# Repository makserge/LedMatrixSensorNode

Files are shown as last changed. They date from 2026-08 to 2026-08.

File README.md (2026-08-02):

# Led Matrix Node

A custom build based on a "LED Music Spectrum Rhythm Lights Voice Sensor 1624 RGB Atmosphere Level Indicator with Clock Display" panel driven by a Seeed XIAO ESP32-S3 Plus. It shows the time, ambient CO₂/temperature, a live audio spectrum analyzer, scrolling alert messages, or MQTT-pushed pixel-art icons; tracks room presence and people via mmWave radar; and is fully controllable and observable over MQTT (with Home Assistant auto-discovery).

---

## Architecture

The firmware is split into independent FreeRTOS tasks, each pinned to a core and communicating through small, mutex/queue-protected shared state rather than globals:

| Task | Core | Responsibility |
|---|---|---|
| `DisplayTask` | 1 | Owns the matrix, view state machine, CO₂ alarm/beep logic, button input, OTA progress rendering |
| `NtpClockTask` | 1 | Keeps wall-clock time via NTP, pushes formatted strings through a queue |
| `MqttTask` | 1 | Connects/reconnects to the broker, publishes sensor + radar data, dispatches incoming commands |
| `SpectrumAnalyzerTask` | 2 (audio priority) | Decodes the audio stream, runs dual FFTs, drives per-band ballistics |
| `Co2Task`, `TempHumTask`, `LightTask`, `LD2412Task`, `LD2450Task` | 0 | Poll their respective sensors on independent intervals |
| `LedMatrix` internal display engine | 1 | Bit-bangs the panel's HUB75-style interface from double-buffered R/G/B column data |

I²C sensors (SCD4x CO₂, HTU21D temp/humidity, BH1750 light) share the bus behind a single `i2cMutex` (`i2c_mutex.h`) — every I²C transaction, including `begin()` calls, must be wrapped in `xSemaphoreTake`/`Give`.

Rendering follows a **Command Pattern**: each screen lives in its own `src/screen_*.cpp` file (`screen_clock`, `screen_temp`, `screen_co2`, `screen_spectrum`, `screen_alert`, `screen_ota`, `screen_icon`), all declared through one `screen_renderers.h` registry and dispatched from a single `switch` in `displayTask`.

**Background task handles** are centralized in `task_registry.h`/`.cpp` so the whole sensor/MQTT layer can be suspended and resumed as a unit (used during OTA — see below).

---

## Hardware / Pinout

Board: Seeed XIAO ESP32-S3 Plus (Arduino-style `Dx` pin aliases used for most GPIO), driving the 1624 RGB Atmosphere Level Indicator panel's HUB75-style interface.

| Function | Pin(s) |
|---|---|
| Panel RGB data | `R1`=42, `G1`=D3, `B1`=10 |
| Panel clock/latch/enable | `CLK`=D4, `LAT`=D6, `OE`=D5 |
| Panel row address | `A`=D0, `B`=38, `C`=39 |
| Panel chip-selects | `L_EN`=40, `M_EN`=41, `R_EN`=D2 |
| I²C bus (CO₂/temp/light sensors) | `SDA`=12, `SCL`=7 |
| Beeper | 13 |
| Mode button | D9 (`INPUT_PULLUP`) |
| Power toggle button | D10 (`INPUT_PULLUP`) |
| LD2412 presence (digital) | D1 |
| LD2450 UART (Serial1) | `RX`=11, `TX`=D7 @ 256000 baud |

The panel is driven by a **hand-rolled HUB75-style engine** (`led_matrix.cpp`/`.h`): it bit-bangs GPIO registers directly, splits the 24-column panel across 3 chip-select groups of 8, and controls brightness with on-time PWM within a fixed 180µs column window. Text is rendered with a hand-authored 4×14 PROGMEM font (`font_4x14.h`) covering `0–9`, `A–Z`, `:`, `.`, and a degree glyph mapped to `*` in source strings.

---

## Configuration

Copy `secrets.example.h` to `secrets.h` and fill in your own values (git-ignored):

```cpp
static const char* const MQTT_HOST = "192.168.x.x";
static const char* const MQTT_USER = "your_mqtt_user";
static const char* const MQTT_PASS = "your_mqtt_password";
static const char* const AUDIO_STREAM_URL = "http://192.168.x.x:8000/stream.wav";
static const char* const WIFI_BACKUP_SSID = "backup-network";
static const char* const WIFI_BACKUP_PASS = "backup-password";
```

`WIFI_BACKUP_SSID`/`PASS` are optional — leave blank to disable the fallback network.

### Library dependencies

`WiFiManager`, `ElegantOTA`, `ESPAsyncWebServer`, `PubSubClient`, `ArduinoJson`, `Preferences`, `SensirionI2cScd4x`, `HTU21D`, `BH1750`, `LD2450`, and `AudioTools` (with `AudioRealFFT`).

---

## Display & View Management

- **Views:** `VIEW_TIME`, `VIEW_TEMP_DATA`, `VIEW_CO2`, `VIEW_SPECTRUM`, `VIEW_CUSTOM_MSG`, `VIEW_CUSTOM_ICON`.
- **Persistence:** the active view *and* the clock color are stored in NVS (`Preferences`, namespace `"display"`) and restored on boot. Transient views (custom message, icon, CO₂ popup) are set via `setView()` and are **never** persisted — only deliberate mode changes via `selectView()` (button/MQTT) update the boot-time default.
- **Auto-return:** temp/CO₂ auto-return after `DISPLAY_AUTO_RETURN_DELAY_MS` (5s). Scrolling messages and icons expire after their own duration or (for messages) 3 full scroll passes.
- **View arbitration:**
  - Spectrum's automatic entry **cannot interrupt** an active custom message or icon still within its display window.
  - Once the user manually switches to a view other than spectrum (button or MQTT `display/mode`), spectrum's automatic re-entry is **suppressed** until the user manually selects spectrum again — audio staying active no longer yanks the display back.
  - Custom messages and MQTT-pushed icons **restore the view that was active before they interrupted it** (including spectrum) once they expire, rather than always falling back to the clock — the same pattern the CO₂ alarm popup already used. Manually cycling to temp/CO₂ via the button still auto-returns to the clock after 5s, unchanged — that's deliberate browsing, not an interruption.
- **Buttons:** mode button cycles `TIME → TEMP → CO2 → SPECTRUM` (300ms debounce); power button blanks/wakes the panel without stopping any background task.
- **Persistent clock color:** MQTT-settable, survives reboots (see [MQTT Topics](#mqtt-topics)).
- **No artificial startup delay** — `displayTask` initializes the matrix immediately rather than waiting a fixed period before starting.

## RLE Icon Display

Pixel-art icons can be pushed to the panel over MQTT as a compact run-length-encoded binary payload:

**Topic:** `led_matrix_node/display/icon`
**Payload:** repeating runs — `[runLength, r, g, b]`, one byte each — covering up to 384 pixels (24×16) in row-major order. Colors are quantized to the panel's native 3-bit palette (each channel thresholds at >127).

Two payload formats are accepted, auto-detected:

- **ASCII hex string** (recommended — plain text, works from MQTT Explorer's payload box or Home Assistant's `mqtt.publish` service with no binary handling needed):
  ```
  C0000000C0FFFFFF
  ```
  (top half of the panel black, bottom half white — 192 black pixels + 192 white pixels = 384 total)

  ```yaml
  # Home Assistant automation action
  action: mqtt.publish
  data:
    topic: led_matrix_node/display/icon
    payload: "C0000000C0FFFFFF"
  ```

- **Raw binary** is also accepted (auto-detected) for programmatic publishing, but the hex-string format above is recommended for all use cases — it works identically from a script, MQTT Explorer, or Home Assistant with no extra encoding step.

The icon is buffered server-side and **redrawn every frame** while `VIEW_CUSTOM_ICON` is active (it does not persist as the boot default, and is protected from spectrum's automatic re-entry the same way custom messages are), then auto-returns to the previous rotation after `ICON_DISPLAY_DURATION_MS` (15s).

> ⚠️ **If using raw binary instead of the hex format above:** `mosquitto_pub -m "\xc0\x00..."` does **not** interpret `\xNN` as byte escapes — it sends those characters literally as ASCII text. Use `printf '\xc0\x00...' | mosquitto_pub -t ... -l` (or `-f` with a file), or build the payload as real bytes in a script. This is exactly the trap the hex-string format above avoids — prefer it unless you have a specific reason to send raw binary.

### Example icons

Two ready-to-use icons for a washing-machine status use case — publish either directly to `led_matrix_node/display/icon`.

**Washing in progress:**
```
.....#############......
.....#...........#......
.....#...........#......
.....#...........#......
.....#...........#......
.....#############......
.....#...........#......
.....#.....#.....#......
.....#....#.#....#......
.....#...#...#...#......
.....#..#.....#..#......
.....#...#GGG#...#......
.....#....#G#....#......
.....#.....#.....#......
.....#...........#......
.....#############......
```
```
050000000D00FF000B0000000100FF000B0000000100FF000B0000000100FF000B0000000100FF000B0000000100FF000B0000000100FF000B0000000100FF000B0000000100FF000B0000000D00FF000B0000000100FF000B0000000100FF000B0000000100FF00050000000100FF00050000000100FF000B0000000100FF00040000000100FF00010000000100FF00040000000100FF000B0000000100FF00030000000100FF00030000000100FF00030000000100FF000B0000000100FF00020000000100FF00050000000100FF00020000000100FF000B0000000100FF00030000000100FF00030000FF0100FF00030000000100FF000B0000000100FF00040000000100FF00010000FF0100FF00040000000100FF000B0000000100FF00050000000100FF00050000000100FF000B0000000100FF000B0000000100FF000B0000000D00FF0006000000
```

**Washing complete** (same machine, shifted left with a checkmark badge alongside):
```
.#############..........
.#...........#..........
.#...........#..........
.#...........#..........
.#...........#........##
.#############.......##.
.#...........#.......##.
.#.....#.....#......##..
.#....#.#....#......##..
.#...#...#...#..#..##...
.#..#.....#..#..##.##...
.#...#GGG#...#...###....
.#....#G#....#...###....
.#.....#.....#....#.....
.#...........#..........
.#############..........
```
```
010000000D00FF000B0000000100FF000B0000000100FF000B0000000100FF000B0000000100FF000B0000000100FF000B0000000100FF000B0000000100FF000B0000000100FF00080000000200FF00010000000D00FF00070000000200FF00020000000100FF000B0000000100FF00070000000200FF00020000000100FF00050000000100FF00050000000100FF00060000000200FF00030000000100FF00040000000100FF00010000000100FF00040000000100FF00060000000200FF00030000000100FF00030000000100FF00030000000100FF00030000000100FF00020000000100FF00020000000200FF00040000000100FF00020000000100FF00050000000100FF00020000000100FF00020000000200FF00010000000200FF00040000000100FF00030000000100FF00030000FF0100FF00030000000100FF00030000000300FF00050000000100FF00040000000100FF00010000FF0100FF00040000000100FF00030000000300FF00050000000100FF00050000000100FF00050000000100FF00040000000100FF00060000000100FF000B0000000100FF000B0000000D00FF000A000000
```

(`#`=green outline, `G`=blue door accent — `.` renders as black/off)

## NTP Clock

Syncs via `configTzTime` against `pool.ntp.org`. Formats `HH:MM` with a blinking colon; shows `SYNC` until the first successful fix.

## Environmental Sensors

- **CO₂ (Sensirion SCD4x):** 0-ppm glitch rejection, watchdog restart on stalled measurement cycles.
- **Temperature/Humidity (HTU21D):** sanity-bounded reads (`hum < 101%`, `temp > -40°C`).
- **Ambient Light (BH1750):** drives automatic matrix brightness via a smoothed exponential curve, low-pass filtered to avoid visible jumps.

## CO₂ Alarm System

Hysteresis band between `CO2_WARNING_THRESHOLD` (1000ppm) and `CO2_ALARM_LOW_THRESHOLD` (900ppm); a recurring red popup with quiet-hours-gated beeping (08:00–22:00), safety-timeout-bounded so it can never get stuck on screen.

## Audio Spectrum Analyzer

Dual-resolution FFT (2048-pt bass / 1024-pt mid-high) driving a 24-column VU-style display with Gaussian-weighted log-frequency bands, noise gating, compression, adaptive AGC, and tilt EQ. Auto-enters `VIEW_SPECTRUM` on active audio (respecting the view-arbitration rules above) and fades to sleep on sustained silence.

**Peak-dot physics** are ported from [`audioMotion-analyzer`](https://github.com/hvianna/audioMotion-analyzer)'s gravity-based fall model: rather than dropping at a fixed rate, each band's peak indicator accelerates continuously after `BALLISTICS_PEAK_HOLD_MS` (700ms hold), governed by `SPECTRUM_PEAK_GRAVITY_STEPS_PER_S2` — tune this constant to make peaks fall faster/slower/more "floaty". The audio transport (HTTP stream ingestion, dual-FFT band mapping) and silence-detection state machine (rolling average, sleep-fade, presence-aware view auto-return) are unchanged from the existing design, which was already a log-frequency, Gaussian-weighted mapping in its own right.

## mmWave Radar

**LD2412** — binary presence on a single GPIO. **LD2450** — up to 3 tracked targets over UART with a sign-fix for its two's-complement quirk and a watchdog that fully re-inits the link on stall (UART desync doesn't self-heal the way the frame-redrawn matrix does).

## WiFi & OTA

- `WiFiManager` captive portal (180s timeout) for first-time setup, followed by an automatic **backup network** attempt (`WIFI_BACKUP_SSID`/`PASS`, `WIFI_BACKUP_TIMEOUT_MS` = 15s) if the primary/portal path fails, before finally restarting.
- Post-connect, the panel shows the assigned IP address (green, 15s) — protected from being interrupted by spectrum auto-entry.
- **OTA updates (`ElegantOTA` at `/update`)** now take over the whole node:
  - The panel shows a static **"OTA"** for the entire transfer, then automatically resumes whatever view was active beforehand — no explicit "restore" logic needed, since the underlying view state is simply untouched while the OTA flag is set.
  - All background tasks are suspended for the duration of the update and resumed afterward — sensors/MQTT (`task_registry.h`) *and* the audio pipeline (stream ingestion, ballistics, spectrum view-switching), freeing CPU and I²C/UART/network bandwidth for the flash write.
  - Buttons, CO₂ alarm logic, and normal view rendering are all paused until the update finishes.
  - **`LedMatrix::displayTaskEngine` is `IRAM_ATTR`, and its pin toggling uses `gpio_ll_set_level()` instead of `digitalWrite()`.** ESP32 flash writes briefly disable both cores' instruction cache; `IRAM_ATTR` on the function alone isn't sufficient, since `digitalWrite()` is a real call out to code that may itself live in flash — if that call stalls mid-refresh with OE left blanked, the panel visibly blinks for the stall's duration. `gpio_ll_set_level()` is a `static inline` register accessor with no external call, so it inherits the caller's IRAM residency and stays safe throughout an OTA write.
- `/wifi-reset` clears saved WiFi credentials and reboots into the config portal.

---

## MQTT Topics

### Commands (subscribe)

| Topic | Payload | Effect | Example |
|---|---|---|---|
| `led_matrix_node/display/mode` | `time` \| `temp` \| `co2` \| `spectrum` | Selects a view, persists across reboots | `mosquitto_pub -t led_matrix_node/display/mode -m "co2"` |
| `led_matrix_node/display/message` | text (≤31 chars, auto-uppercased) | Scrolling red alert, up to 15s or 3 passes | `mosquitto_pub -t led_matrix_node/display/message -m "Package delivered"` |
| `led_matrix_node/display/power` | `1` \| `0` | Panel on/off | `mosquitto_pub -t led_matrix_node/display/power -m "0"` |
| `led_matrix_node/display/color` | `RRGGBB` / `#RRGGBB` / `r,g,b` | Sets and persists the clock color | `mosquitto_pub -t led_matrix_node/display/color -m "FF8800"` |
| `led_matrix_node/display/icon` | RLE hex string (see above) | Shows a pixel-art icon for 15s | see examples above |
| `led_matrix_node/beeper` | any | Single 100ms beep | `mosquitto_pub -t led_matrix_node/beeper -m "1"` |

### State (publish)

| Topic | Format | Interval | Notes |
|---|---|---|---|
| `led_matrix_node/sensors/state` | `{"co2":812,"temp":21.4,"hum":47.2,"lux":18.6}` | 10s | Skipped while `co2 == 0` |
| `led_matrix_node/sensors/status` | `online` / `offline` | on connect / LWT | Retained |
| `led_matrix_node/radar/ld2412` | `1` / `0` | 1s | Retained |
| `led_matrix_node/radar/ld2450` | `{"targets":[...],"count":N}` | 1s | Up to 3 targets |

```bash
mosquitto_sub -v -t 'led_matrix_node/#'
```

### Home Assistant Auto-Discovery

Retained discovery configs are published under `homeassistant/sensor/Led_Matrix_Node_{id}/config` for `co2`, `temp`, `hum`, `lux` on every broker connection.

---

## Key Tunables (`constants.h`)

| Category | Constant | Value |
|---|---|---|
| Display | `DISPLAY_AUTO_RETURN_DELAY_MS` | 5000ms |
| WiFi | `WIFI_CONFIG_TIMEOUT` / `WIFI_BACKUP_TIMEOUT_MS` | 180s / 15000ms |
| WiFi | `WIFI_IP_DISPLAY_DURATION_MS` | 15000ms |
| OTA | `OTA_TEXT_DISPLAY_MS` | 2000ms |
| Icon | `ICON_DISPLAY_DURATION_MS` | 15000ms |
| CO₂ Alarm | `CO2_WARNING_THRESHOLD` / `CO2_ALARM_LOW_THRESHOLD` | 1000 / 900 ppm |
| CO₂ Alarm | `CO2_ALARM_START_HOUR`–`END_HOUR` | 08:00–22:00 |
| Matrix | `MATRIX_WIDTH` / `MATRIX_HEIGHT` | 24 / 16 |
| MQTT | `MQTT_PUBLISH_INTERVAL` / `MQTT_RADAR_PUBLISH_INTERVAL` | 10000ms / 1000ms |
| Radar | `LD2450_DATA_TIMEOUT_MS` | 10000ms |
| Spectrum | `SPECTRUM_AGC_TARGET_LED`, `SPECTRUM_TILT_DB_PER_OCTAVE` | 8.0, 3dB/oct |
| Spectrum | `SPECTRUM_PEAK_GRAVITY_STEPS_PER_S2` | 220.0 (steps/s²) |

See `constants.h` for the full list.

---

## Security Notes

- `secrets.h` contains live credentials (primary + backup WiFi, MQTT, audio stream URL) — keep it out of version control.
- The web UI (`/`, `/update`, `/wifi-reset`) is unauthenticated on the local network.

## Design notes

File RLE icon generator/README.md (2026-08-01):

# 24x16 RLE Icon Editor and MQTT Publisher

A lightweight, high-utility web application designed to create, edit, and convert custom pixel artwork into custom Run-Length Encoded (RLE) Hex streams. It is specifically optimized for hardware displays with rectangular pixels (2:1 width-to-height ratio) and features a bidirectional compiler that can both pack canvas data and unpack/decode existing RLE strings back into editable pixels.

---

## Features

- **Interactive 24x16 Matrix Editor:** Click and drag to paint pixel art in real-time. The browser UI grid matches the hardware's 2:1 rectangular aspect ratio natively (What You See Is What You Get).
- **Instant Drag and Drop Image Converter:** Drop standard images (.png, .jpg, .webp) to automatically downscale and map them onto the 24x16 display grid.
- **Advanced Back-Converter / Decompressor:** Paste a raw RLE hex string (or an entire mosquitto_pub terminal command line) to unpack it back into fully editable grid pixels.
- **Custom Real-Time RLE Compiler:** Generates compact data streams using a 1-byte count + 3-byte RGB structure.
- **Live MQTT Command Generator:** Auto-interpolates Host, Username, and Password fields directly into a standalone shell execution script.
- **Persistent Configuration Storage:** Saves your MQTT configuration variables locally using localStorage so you never have to re-type them.

---

## Project Structure

To run the application, ensure the following 3 core files are saved in the exact same directory. No local web server or terminal configuration is required to execute the workspace:

```text
├── rle_icon_generator.html   # Main application interface and engine
├── style.css                 # Dark-mode workspace and fluid 2:1 grid layout styling
└── app.js                    # Core logic (drawing, RLE compression/decompression, image scaling)
```

---

## Understanding the RLE Hex Format

The compiler uses a simple 4-Byte Packet Compression Logic optimized for hardware components (like ESP32/Arduino display drivers):
- **1st Byte (2 Hex Characters):** The Run Count (Repetition depth up to 255 / Hex FF).
- **2nd, 3rd, 4th Byte (6 Hex Characters):** The 24-bit RGB Color Code in UpperCase Hex format.

### Example:
- **`1E000000`** translates to `1E` (30 in decimal) pixels of `000000` (Pure Black).
- **`0CFFFFFF`** translates to `0C` (12 in decimal) pixels of `FFFFFF` (Pure White).

---

## Technical Limitations and Pixel Aspect Ratio

While the drag-and-drop workflow is completely automated, converting standard graphics into a restrictive 24x16 grid with 2:1 rectangular pixels requires specific data handling considerations:

### 1. 2:1 Pixel Aspect Ratio (Physical 3:1 Matrix Screen)
- **The 2:1 Rule:** Each pixel on your physical LED matrix is twice as wide as it is tall (2w x 1h). 
- **Physical Aspect Ratio:** Although the grid resolution is 24x16 (a 3:2 index count), the physical shape of the running screen is 3:1 widescreen (24 x 2 : 16 x 1 = 48:16 = 3:1).
- **Image Distortion Warning:** If you drop a standard 3:2 square-pixel image into the converter, it will appear stretched horizontally by 200% when displayed on your physical hardware. For correct, un-distorted deployment, your source image needs to look squeezed horizontally before conversion.

### 2. Resolution and Forced Scaling
- **Strict Matrix Fit:** The engine forces any input image to fit a strict 24x16 matrix pixel array, regardless of its original size. Input images are directly mapped to the 24x16 color array indices without letterboxing or cropping. 

### 3. Downsampling Noise (Anti-Aliasing)
- **Bilinear Blur:** Browsers use smooth anti-aliasing algorithms when downscaling. If you upload a massive photo, fine lines, text, or intricate details will blur together into combined average color blocks.
- **Best Practice:** The converter works best on crisp, low-resolution pixel art templates designed natively for your hardware profile.

### 4. Color Depth and Transparency
- **Raw 24-bit Output:** The code captures exactly what the browser samples and outputs true 24-bit RGB Hex (000000 to FFFFFF). No palette quantization or color reduction is applied.
- **Forced Black Canvas Background:** The hidden rendering scratchpad canvas is pre-filled with pure black (#000000) right before printing your image over it. Transparent .png areas will merge into pure black.

### 5. RLE Run Length Multiplier Cap
- **255 Pixel Max Sequence Chunks:** A single run-length packet can only count up to 255 (FF in hex) before it must close out the sequence chunk and start a new packet string segment.
- **Byte Chunks:** Because your entire display consists of 384 pixels total (24 x 16 = 384), a completely solid image (like pure black or solid red) will always output exactly two packet clusters in the hex code text area instead of a single string line block.

---

## How to Use

### 1. Launching the App
Simply open rle_icon_generator.html in any modern web browser. It runs seamlessly directly off your filesystem (file:///) without local server overhead.

### 2. Configuration Setup
Enter your network credentials into the MQTT Configuration Block at the top of the interface. Modifying any character here updates the command line text output instantly.

### 3. Creating and Editing Icons

#### Method A: Drawing Manually
1. Select a color using the Brush Color picker input.
2. Left-click and hold your mouse button down while dragging across the 24x16 Matrix Grid Canvas.
3. Use the Clear (Black) button to instantly reset your workspace canvas to default solid black (1E000000).

#### Method B: Drag and Drop Converter
1. Take any compatible image file from your computer.
2. Drag and drop it into the dashed blue area labeled: "Drop an image here or click to upload".
3. The image processing engine will parse it into a clean 24x16 matrix representation.

#### Method C: Importing and Decoding Existing RLE Codes
1. Paste a raw RLE hex string into the "Raw RLE Hex Code / Import Stream" text box at the bottom.
2. Alternative: You can paste a full terminal command (e.g., mosquitto_pub ... -m "1E000000..."). The engine's Regex string parser will automatically strip the wrapper and extract the payload.
3. Click the green "Import and Decode to Grid" button. The matrix canvas will instantly render the icon, allowing you to manipulate and modify it manually.

### 4. Deploying the Payload
- Look at the bottom Mosquitto Pub Shell Command text area box.
- Click "Copy Command" to copy the generated script directly onto your clipboard.
- Open your terminal or bash prompt and paste the script line to publish your icon stream instantly to your matrix nodes over the led_matrix_node/display/icon topic.

---

## Pro-Tip for Perfect Rectangular Pixel Conversions

To design icons that display with perfect proportions on your 2:1 pixel aspect ratio hardware matrix:

1. Open your pixel art editor (e.g., Aseprite, Photoshop, or Piskel).
2. Create a canvas sized exactly 48x16 pixels (this matches the true physical aspect ratio of your screen).
3. Draw your artwork normally within this 48x16 space so that circles look circular and proportions look correct.
4. When finished, resize/scale the image down to exactly 24x16 pixels using Nearest Neighbor resampling (disable linear interpolation/smoothing).
5. The resulting image will look horizontally squished on your computer screen. Save this 24x16 squished image as a PNG.
6. Drag and drop this PNG into the generator app. The index mapping will be pixel-perfect, and when sent to your matrix display node, the 2:1 hardware pixels will stretch the image back out to its original, perfectly proportioned look!

---

## License
This tool is open-source and free to be customized for your embedded hardware and home automation projects.

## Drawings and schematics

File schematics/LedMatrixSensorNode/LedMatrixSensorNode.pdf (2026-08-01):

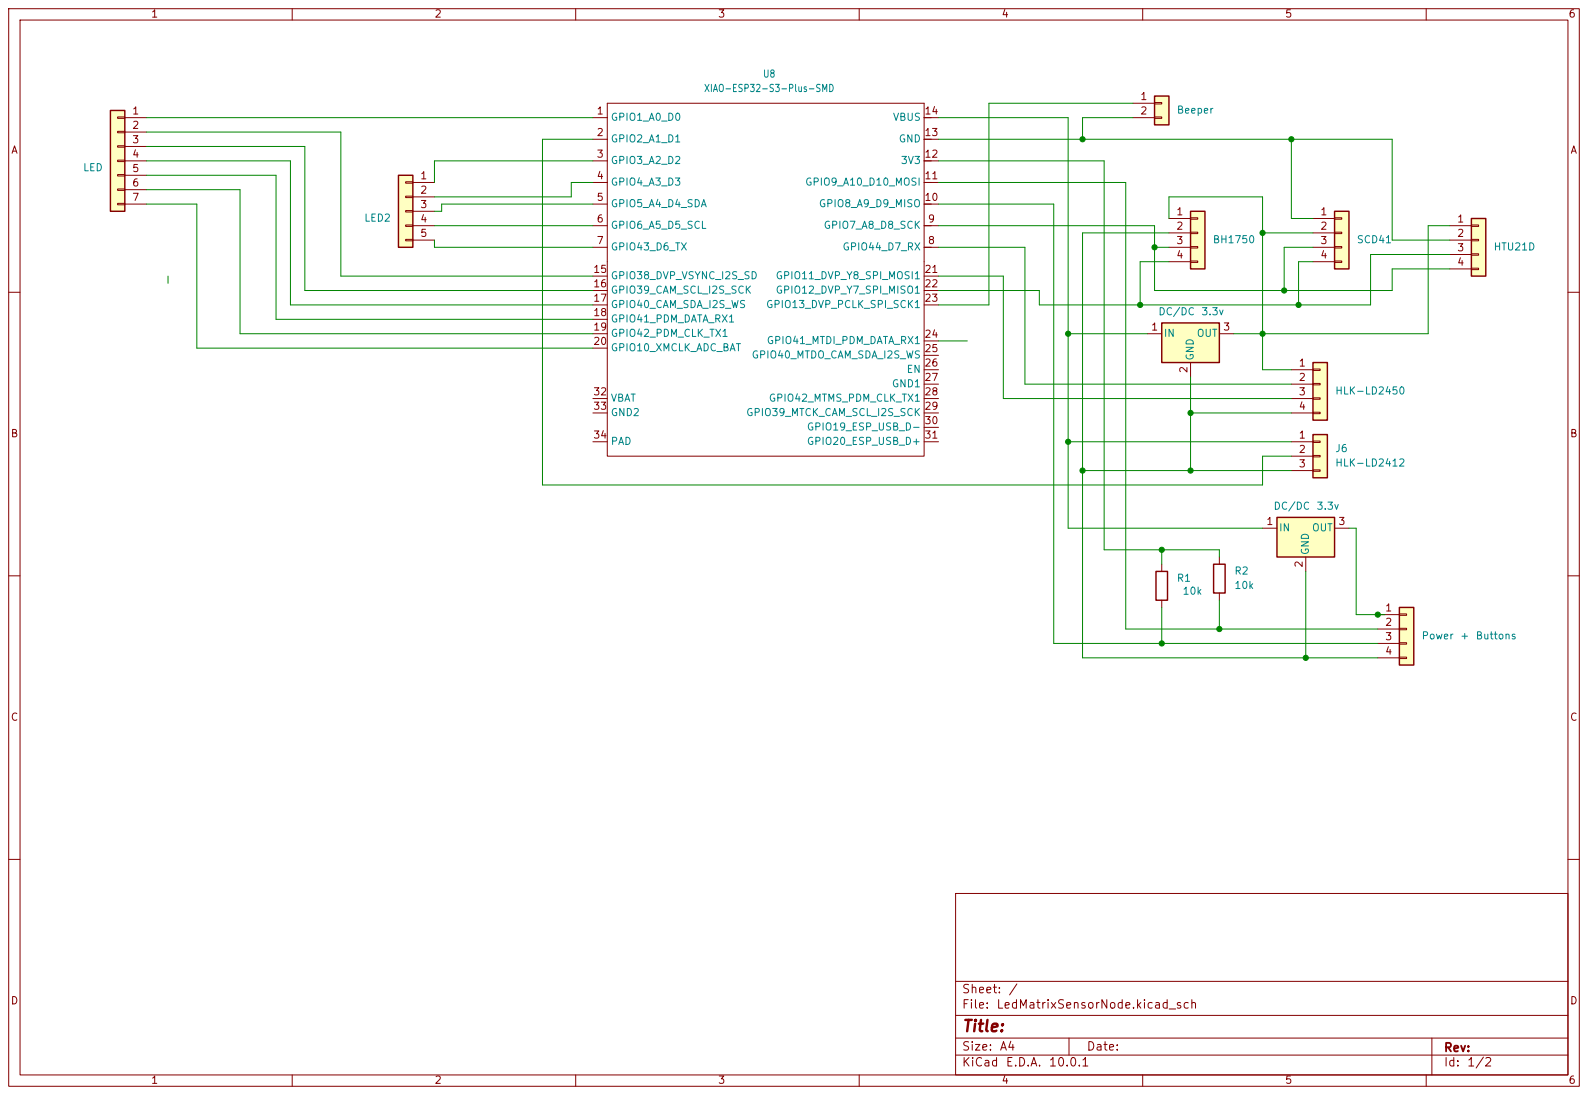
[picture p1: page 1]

Size: A4 | Rev:
KiCad E.D.A. 10.0.1 | Id: 1/2

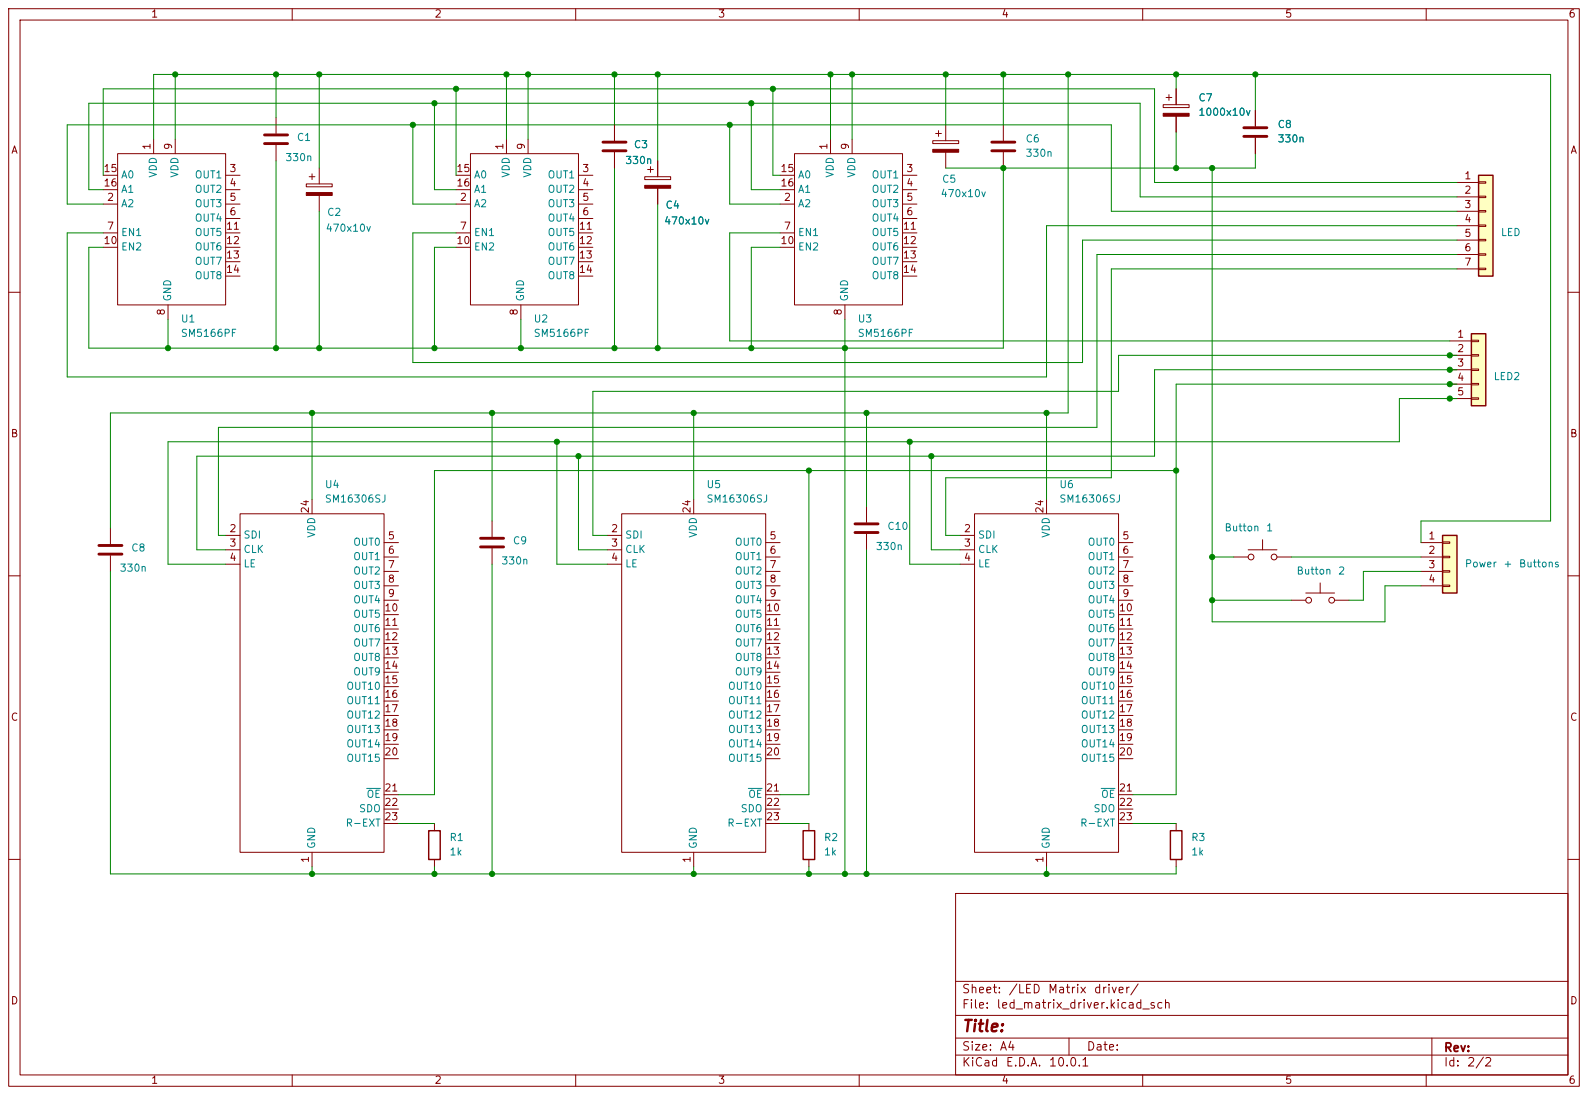
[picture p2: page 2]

Sheet: /LED Matrix driver/
File: led_matrix_driver.kicad_sch
Title:

Size: A4 | Rev:
KiCad E.D.A. 10.0.1 | Id: 2/2

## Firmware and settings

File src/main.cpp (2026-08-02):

#include <Arduino.h>
#include <Wire.h>
#include "wifi_management.h"
#include "constants.h"
#include "co2_sensor.h"
#include "temp_humidity_sensor.h"
#include "light_sensor.h"
#include "spectrum_analyzer.h"
#include "display_manager.h"
#include "mqtt_manager.h"
#include "ntp_clock.h"
#include "ld2412_sensor.h"
#include "ld2450_sensor.h"
#include "i2c_mutex.h"

void setup() {
    Serial.begin(115200);

    initI2CMutex();

    Wire.begin(I2C_SDA_PIN, I2C_SCL_PIN);

    initDisplayTask();
    initWiFiManagement();
    initSpectrumAnalyzerTask();
    initCo2SensorTask();
    initTempHumiditySensorTask();
    initNtpClockTask();
    initLightSensorTask();
    initLd2412SensorTask();
    initLd2450SensorTask();
    initMqttTask();
}

void loop() {
}

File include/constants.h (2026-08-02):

#ifndef CONSTANTS_H
#define CONSTANTS_H

#include <Arduino.h>
#include "pins.h"
#include "secrets.h"

static const uint16_t MQTT_PORT = 1883;
static const char* MQTT_CLIENT_ID = "Led_Matrix_Node";
static const unsigned long MQTT_PUBLISH_INTERVAL = 10000;
static const unsigned long MQTT_RADAR_PUBLISH_INTERVAL = 1000;

static const char* MQTT_STATE_TOPIC      = "led_matrix_node/sensors/state";
static const char* MQTT_STATUS_TOPIC     = "led_matrix_node/sensors/status";
static const char* MQTT_DISCOVERY_PREFIX = "homeassistant";

static const char* MQTT_CONFIG_TOPIC_TPL = "%s/sensor/%s_%s/config";

static const char* const MQTT_DISPLAY_MODE_TOPIC  = "led_matrix_node/display/mode";
static const char* const MQTT_DISPLAY_MSG_TOPIC   = "led_matrix_node/display/message";
static const char* const MQTT_DISPLAY_POWER_TOPIC = "led_matrix_node/display/power";
static const char* const MQTT_DISPLAY_COLOR_TOPIC = "led_matrix_node/display/color";
static const char* const MQTT_DISPLAY_ICON_TOPIC  = "led_matrix_node/display/icon";

static const char* const MQTT_BEEPER_TOPIC        = "led_matrix_node/beeper";

static const char* const MQTT_LD2412_TOPIC = "led_matrix_node/radar/ld2412";
static const char* const MQTT_LD2450_TOPIC = "led_matrix_node/radar/ld2450";

static const unsigned long CO2_SENSOR_INTERVAL = 30000;
static const unsigned long CO2_DATA_TIMEOUT_MS = 90000;
static const unsigned long LIGHT_SENSOR_INTERVAL = 2000;
static const unsigned long TEMP_HUM_SENSOR_INTERVAL = 15000;
static const unsigned long LD2412_SENSOR_INTERVAL = 500;
static const unsigned long LD2450_SENSOR_INTERVAL = 50;

static const unsigned long LD2450_DATA_TIMEOUT_MS = 10000;

static const uint8_t CO2_SENSOR_ADDRESS = 0x62;

static const char* const WIFI_PORTAL_NAME = "Led Matrix Node";
static const uint16_t WIFI_CONFIG_TIMEOUT = 180;
static const unsigned long WIFI_BACKUP_TIMEOUT_MS = 15000;
static const unsigned long WIFI_IP_DISPLAY_DURATION_MS = 15000;

static const uint8_t DISPLAY_BRIGHTNESS = 20;

static const uint32_t LD2450_STARTUP_DELAY_MS = 5000;
static const uint32_t SENSOR_TASK_STACK_SIZE = 4096;
static const uint8_t SENSOR_TASK_PRIORITY = 1;

static const uint32_t MQTT_TASK_STACK_SIZE = 8192;
static const uint8_t MQTT_TASK_PRIORITY = 1;

static const char* const NTP_SERVER = "pool.ntp.org";
static const char* const TIME_ZONE  = "CET-1CEST,M3.5.0,M10.5.0/3";

static const uint32_t CLOCK_TASK_STACK_SIZE = 3072;
static const uint8_t CLOCK_TASK_PRIORITY = 1;

static const UBaseType_t CLOCK_QUEUE_LENGTH = 1;

enum DisplayView {
    VIEW_TIME,
    VIEW_TEMP_DATA,
    VIEW_CO2,
    VIEW_SPECTRUM,
    VIEW_CUSTOM_MSG,
    VIEW_CUSTOM_ICON
};

static const uint8_t MATRIX_WIDTH = 24;
static const uint8_t MATRIX_HEIGHT = 16;
static const uint16_t MATRIX_TOTAL_PIXELS = (uint16_t)MATRIX_WIDTH * MATRIX_HEIGHT;

static const unsigned long ICON_DISPLAY_DURATION_MS = 15000;
static const unsigned long OTA_TEXT_DISPLAY_MS = 2000;

static const uint32_t AUDIO_TASK_STACK_SIZE = 8192;
static const uint8_t AUDIO_TASK_PRIORITY = 2;

static const uint8_t STREAM_TASK_PRIORITY = 4;

static const uint32_t BALLISTICS_TASK_STACK_SIZE = 3072;
static const uint8_t BALLISTICS_TASK_PRIORITY = AUDIO_TASK_PRIORITY + 1;

static const uint32_t MQTT_MSG_MAX_LEN = 32;

static const float LUX_MIN_THRESHOLD = 2.0f;
static const float LUX_MAX_THRESHOLD = 30.0f;
static const uint8_t MATRIX_MIN_BRIGHTNESS = 20;
static const uint8_t MATRIX_MAX_BRIGHTNESS = 255;

static const uint32_t DISPLAY_TASK_STACK_SIZE = 4096;
static const uint8_t DISPLAY_TASK_PRIORITY = 1;

static const uint16_t SPECTRUM_FFT_LOW_SIZE = 2048;
static const uint16_t SPECTRUM_FFT_LOW_STRIDE = 1470;

static const uint16_t SPECTRUM_FFT_HIGH_SIZE = 1024;
static const uint16_t SPECTRUM_FFT_HIGH_STRIDE = 441;

static const uint8_t SPECTRUM_LOW_BAND_COUNT = 10;

static const float SPECTRUM_REF_FLOOR_MAG = 0.7f;
static const float SPECTRUM_REF_RISE_ALPHA = 0.05f;
static const float SPECTRUM_REF_FALL_ALPHA = 0.01f;
static const float SPECTRUM_REF_SCALE = 0.35f;

static const float SPECTRUM_ABS_SILENCE_MAG = 0.15f;
static const uint32_t SPECTRUM_SILENCE_AVG_WINDOW_MS = 2000;
static const uint32_t SPECTRUM_SLEEP_FADE_MS = 2000;

static const uint32_t AUDIO_SILENCE_TIMEOUT_MS = 2000;
static const uint32_t MIN_SPECTRUM_DISPLAY_MS = 5000;
static const uint32_t SPECTRUM_PRESENCE_OVERRIDE_MS = 5000;

static const float SPECTRUM_NOISE_GATE_DBFS = -45.0f;

static const float SPECTRUM_DB_WINDOW = 40.0f;
static const float SPECTRUM_DB_PER_STEP = SPECTRUM_DB_WINDOW / 16.0f;

static const float SPECTRUM_COMPRESSION_THRESHOLD_DBFS = -12.0f;
static const float SPECTRUM_COMPRESSION_RATIO = 2.0f;

static const float SPECTRUM_AGC_TARGET_LED = 8.0f;

static const float SPECTRUM_TILT_DB_PER_OCTAVE = 3.0f;
static const float SPECTRUM_TILT_REFERENCE_HZ = 1000.0f;

static const uint32_t BALLISTICS_TICK_MS = 10;

static const float BALLISTICS_ATTACK_COEFF = 0.0f;

static const float BALLISTICS_DECAY_COEFF = 0.75f;
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

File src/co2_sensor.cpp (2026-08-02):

#include "co2_sensor.h"

Co2Sensor co2Sensor;

void Co2Sensor::begin() {
    xSemaphoreTake(i2cMutex, portMAX_DELAY);
    _scd4x.begin(Wire, CO2_SENSOR_ADDRESS);
    _scd4x.stopPeriodicMeasurement();
    _scd4x.startPeriodicMeasurement();
    xSemaphoreGive(i2cMutex);
    _lastDataReadyMs = millis();
}

void Co2Sensor::update() {
    bool isDataReady = false;
    uint16_t status;
    uint32_t nowMs = millis();

    xSemaphoreTake(i2cMutex, portMAX_DELAY);
    status = _scd4x.getDataReadyStatus(isDataReady);
    xSemaphoreGive(i2cMutex);

    if (status == 0 && isDataReady) {
        uint16_t co2;
        float temp, hum;
        uint16_t readStatus;

        xSemaphoreTake(i2cMutex, portMAX_DELAY);
        readStatus = _scd4x.readMeasurement(co2, temp, hum);
        xSemaphoreGive(i2cMutex);

        if (readStatus == 0) {
            if (co2 > 0) {
                _currentCo2 = co2;
                _currentTemp = temp;
                _currentHum = hum;
                Serial.printf("CO2: %u ppm, T: %.1f, H: %.1f\n", _currentCo2, _currentTemp, _currentHum);
            }
            _lastDataReadyMs = nowMs; // any successful read (even a rejected 0) proves the cycle is alive
        }
    }

    if (nowMs - _lastDataReadyMs >= CO2_DATA_TIMEOUT_MS) {
        Serial.println("[CO2] watchdog: no data for too long, re-initializing sensor");
        xSemaphoreTake(i2cMutex, portMAX_DELAY);
        _scd4x.stopPeriodicMeasurement();
        _scd4x.startPeriodicMeasurement();
        xSemaphoreGive(i2cMutex);
        _lastDataReadyMs = nowMs;
    }
}

void co2SensorTask(void *pvParameters) {
    co2Sensor.begin();

    for (;;) {
        co2Sensor.update();
        vTaskDelay(pdMS_TO_TICKS(CO2_SENSOR_INTERVAL));
    }
}

void initCo2SensorTask() {
    xTaskCreatePinnedToCore(
        co2SensorTask, "CO2Task", SENSOR_TASK_STACK_SIZE, NULL,
        SENSOR_TASK_PRIORITY, &co2TaskHandle, 0   // was NULL
    );
}

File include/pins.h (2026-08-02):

#ifndef PINS_H
#define PINS_H

#include <Arduino.h>

#define R1_PIN  42  // D15
#define G1_PIN  D3  // D3
#define B1_PIN  10  // D16
#define CLK_PIN D4  // D4
#define LAT_PIN D6  // D6
#define OE_PIN  D5  // D5

#define A_PIN    D0 // D0
#define B_PIN    38 // D11
#define C_PIN    39 // D12
#define L_EN_PIN 40 // D13
#define M_EN_PIN 41 // D14
#define R_EN_PIN D2 // D2

#define I2C_SDA_PIN 12 
#define I2C_SCL_PIN 7

// UI Elements
#define BEEPER_PIN          13
#define MODE_BUTTON_PIN     D9 // D9
#define SWITCH_OFF_LED_PIN  D10 // D10

#define RADAR_PRESENCE_PIN   D1

// LD2450 Radar (Hardware Serial 1)
#define RADAR_RX_PIN 11
#define RADAR_TX_PIN D7
#define RADAR_BAUD   256000

#endif

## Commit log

2026-04-12 WIP code and schematics
    [LedMatrixSensorNode.kicad_pcb, LedMatrixSensorNode.kicad_sch, led_matrix_driver.kicad_sch]
2026-05-03 Added WI-Fi config, OTA, CO2, temperature, humidity sensors, MQTT for sensors
    [LedMatrixSensorNode.kicad_sch, led_matrix_driver.kicad_sch, partitions.csv]
2026-05-24 Added led matrix display
2026-05-25 Added MQTT mode, message, beeper, LED clock, temp, CO2, message, auto LED brightness, mode / LED off buttons
    [LedMatrixSensorNode.kicad_sch, led_matrix_driver.kicad_sch, partitions.csv]
2026-08-01 Updated schematics
    [LedMatrixSensorNode.kicad_sch]
2026-08-02 Added LD-2412, LD-2450, updated spectrum analyser
    [partitions.csv]
2026-10-10 Adjusted CO2 sensor related constants
